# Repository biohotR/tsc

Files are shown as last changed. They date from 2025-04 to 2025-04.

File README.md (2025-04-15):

# OpenBook

## Overview

The project was carried out as part of the Computer Systems Testing course and aims to create a detailed 3D model of an E-Book Reader tablet. We worked on both the internal circuit design and the development of the device’s external appearance, using Fusion 360 software provided by Autodesk.

## Bill of Materials
| Componenta | Link | Datasheet |
|---|---|---|
| BUTTON | [Model](https://industry.panasonic.com/global/en/products/control/switch/light-touch/number/evqpuj02k) | [Datasheet](https://www.lcsc.com/datasheet/lcsc_datasheet_2201121800_PANASONIC-EVQPUJ02K_C2936858.pdf) |
| CAPACITOR | [Model](https://componentsearchengine.com/part-view/R0402%201%25%20100%20K%20(RC0402FR-07100KL)/YAGEO) | [Datasheet](//efaidnbmnnnibpcajpcglclefindmkaj/https://www.resistor.com/assets/pdf/0402tstd.pdf) |
| CPH3225A | [Model](https://www.snapeda.com/parts/CPH3225A/Seiko+Instruments/view-part/?ref=eda) | [Datasheet](https://octopart.com/datasheet/cph3225a-seiko-25340571) |
| EVQPUJ02K | [Model](https://industry.panasonic.com/global/en/products/control/switch/light-touch/number/evqpuj02k) | [Datasheet](https://www.lcsc.com/datasheet/lcsc_datasheet_2201121800_PANASONIC-EVQPUJ02K_C2936858.pdf) |
| KP-1608SURCK | [Model](https://www.snapeda.com/parts/KP-1608SURCK/Kingbright/view-part/?ref=search&t=LED%200603) | [Datasheet](//efaidnbmnnnibpcajpcglclefindmkaj/https://media.elv.com/file/107153_led_surck1608_data.pdf) |
| USBLC6-2SC6Y | [Model](https://www.snapeda.com/parts/USBLC6-2SC6Y/STMicroelectronics/view-part/?ref=eda) | [Datasheet](https://www.digikey.com/en/htmldatasheets/production/1375342/0/0/1/usblc6-2sc6y) |
| SD0805S020S1R0 | [Model](https://ro.mouser.com/ProductDetail/KYOCERA-AVX/SD0805S020S1R0?qs=jCA%252BPfw4LHbpkAoSnwrdjw%3D%3D) | [Datasheet](https://www.alldatasheet.com/view.jsp?Searchword=SD0805S&sField=2) |
| PGB1010603MR | [Model](https://www.snapeda.com/parts/PGB1010603MR/Littelfuse/view-part/?ref=eda) | [Datasheet](https://www.alldatasheet.com/view.jsp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) |
| BD5229G-TR  | [Model](https://componentsearchengine.com/part-view/BD5229G-TR/ROHM%20Semiconductor) | [Datasheet](https://www.lcsc.com/datasheet/lcsc_datasheet_2201131330_ROHM-Semicon-BD5229G-TR_C962636.pdf) |
| XC6220A331MR-G | [Model](https://componentsearchengine.com/part-view/XC6220A331MR-G/Torex) | [Datasheet](https://www.alldatasheet.com/view.jsp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) |
| XC6220A331MR-G | [Model](https://componentsearchengine.com/part-view/XC6220A331MR-G/Torex) | [Datasheet](https://www.alldatasheet.com/view.jsp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) |
| USB4110-GF-A  | [Model](https://componentsearchengine.com/part-view/USB4110-GF-A/GCT%20(GLOBAL%20CONNECTOR%20TECHNOLOGY)) | [Datasheet](//efaidnbmnnnibpcajpcglclefindmkaj/https://gct.co/files/drawings/usb4110.pdf) |
| Adafruit | [Model](https://eu.mouser.com/ProductDetail/Adafruit/4208?qs=PzGy0jfpSMtbScLbr0L5dw%3D%3D) | [Datasheet](https://www.arrow.com/en/manufacturers/adafruit-industries/datasheets) |
| Bobina | [Model](https://store.comet.srl.ro/Catalogue/Product/43497/) | [Datasheet](https://www.scribd.com/document/814581278/Datasheet-Bobina) |
| PFMF | [Model](https://www.mouser.co.uk/ProductDetail/EPCOS-TDK/B72520T0350K062?qs=dEfas%2FXlABIszF52uu7vrg%3D%3D) | [Datasheet](https://ro.mouser.com/c/ds/circuit-protection/thermistors/resettable-fuses-pptc/?m=Schurter&series=PFMF) |
| DMG2305UX-7 | [Model](https://componentsearchengine.com/part-view/DMG2305UX-7/Diodes%20Incorporated) | [Datasheet](//efaidnbmnnnibpcajpcglclefindmkaj/https://www.mouser.com/datasheet/2/115/DMG2305UX-266242.pdf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) |
| Si1308EDL-T1-GE3 | [Model](https://componentsearchengine.com/part-view/SI1308EDL-T1-GE3/Vishay) | [Datasheet](https://www.alldatasheet.com/view.jsp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) |
| R0402 | [Model](https://componentsearchengine.com/part-view/R0402%201%25%20100%20K%20(RC0402FR-07100KL)/YAGEO) | [Datasheet](//efaidnbmnnnibpcajpcglclefindmkaj/https://www.resistor.com/assets/pdf/0402tstd.pdf) |
| BME680 | [Model](https://www.snapeda.com/parts/BME680/Bosch/view-part/?welcome=home) | [Datasheet](//efaidnbmnnnibpcajpcglclefindmkaj/https://www.bosch-sensortec.com/media/boschsensortec/downloads/datasheets/bst-bme680-ds001.pdf) |
| SMD Solder | [Model](https://grabcad.com/library/solder-jumpers-1) | [Datasheet]() |
| W25Q512JVEIQ | [Model](https://www.snapeda.com/parts/ESP32-C6-WROOM-1-N8/Espressif+Systems/view-part/?ref=eda) | [Datasheet](//efaidnbmnnnibpcajpcglclefindmkaj/https://www.mouser.com/datasheet/2/949/W25Q512JV_SPI_RevB_06252019_KMS-2487502.pdf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) |
| ESP32-C6-WROOM-1-N8 | [Model](https://www.snapeda.com/parts/ESP32-C6-WROOM-1-N8/Espressif+Systems/view-part/?ref=eda) | [Datasheet](//efaidnbmnnnibpcajpcglclefindmkaj/https://www.mouser.com/catalog/specsheets/Espressif_ESP32_C6_WROOM_1%20_Datasheet_V0.1_PRELIMINARY_en.pdf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) |
| DS3231SN# | [Model](https://www.snapeda.com/parts/DS3231SN%23/Analog+Devices/view-part/?ref=eda) | [Datasheet](https://www.alldatasheet.com/view.jsp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) |
| MAX17048G+T10 | [Model](https://www.snapeda.com/parts/MAX17048G+T10/Analog+Devices/view-part/?ref=eda) | [Datasheet](https://www.alldatasheet.com/view.jsp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) |
| MCP73831T-5ACI/OT | [Model](https://www.mouser.co.uk/ProductDetail/Microchip-Technology/MCP73831T-5ACI-OT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) | [Datasheet](//efaidnbmnnnibpcajpcglclefindmkaj/https://ww1.microchip.com/downloads/en/DeviceDoc/MCP73831-Family-Data-Sheet-DS20001984H.pdf) |

## Hardware Functionality
The designed circuit includes several key components that ensure the full operation of the E-Book Reader:

1. USB-C Connector with ESD Protection
  
 > Responsible for supplying power to the reader via a USB interface, while also incorporating electrostatic discharge protection to ensure safe and stable operation.
 
2. SD Card
 
 > Acts as the primary storage unit for digital books. It functions at 3.3V and interacts with the microcontroller through the SPI communication bus.
 
3. E-Paper Display and supporting modules: Drive Circuit, EPD Header, and Power Module
  
> The EPD connector interfaces with the microcontroller over SPI and links the display to the system. Power is delivered by a dedicated module that provides multiple voltage levels, while the drive circuit generates the waveforms necessary to update the E-Paper screen.
 
4. BME688 Environmental Sensor
  
 > Capable of detecting temperature, humidity, barometric pressure, and air quality. It operates at 3.3V and uses the I2C protocol for data exchange with the microcontroller.

5. DS3231SN Real-Time Clock Module (RTC)
  
 > Maintains accurate timekeeping, even during power loss, thanks to an onboard 32KHz crystal and optional battery backup. Communication is handled via the I2C protocol, connected through the SDA and SCL lines to the ESP32-C6.

6. External 64MB NOR Flash Memory
  
> Provides additional memory space beyond the microcontroller’s internal storage. Suitable for both long-term data retention and temporary caching. It communicates via SPI.

7.	LDO Voltage Regulator
  
> EStabilizes the power supply by delivering a consistent 3.3V output. Its efficiency and low power usage make it well-suited for portable, battery-operated systems.

8. Voltage Supervisor
  
> Ensures the system starts only under safe voltage conditions by continuously monitoring the power supply and blocking startup if voltage levels are insufficient or erratic.

9. Qwiic/Stemma QT Interface
  
> Simplifies sensor and peripheral integration by allowing multiple I2C devices to be linked in series, reducing the need for complex wiring and enabling plug-and-play functionality.

## Microcontroller ESP32-C6
The entire system is built around the ESP32-C6-WROOM microcontroller, a pre-assembled module with a wide range of integrated capabilities.
* The ESP-WROOM-32 board provides a variety of interfaces for connecting external sensors and components. These include I/O pins, SPI, I2C, and UART, which make it highly versatile for different types of applications. It supports Wi-Fi 6 at 2.4 GHz and features Bluetooth 5 along with a built-in antenna for reliable wireless communication.

* The microcontroller interfaces with various peripheral modules using its dedicated pins, each serving specific functions:

### Power and Reset Control
 > The 3V3 pin powers the module, and GND connects to ground. The EN pin must be set to a HIGH level to activate the module and is typically controlled by a reset button.
### USB-C Interface
 > Since the ESP32-C6 has native USB support, the device communicates directly using the USB_D+ and USB_D- lines, which are mapped to GPIO13 and GPIO14 pins. This eliminates the need for an external USB-to-serial converter.
 ### SD Card Module
> The SD card communicates with the ESP32-C6 via the SPI protocol. The necessary pins for this connection are:
GPIO27 (MISO) – data transfer from the card to the microcontroller,
GPIO7 (MOSI) – data sent to the SD card,
GPIO6 (SCK) – clock signal for synchronization,
GPIO4 (SS_SD) – chip select for the SD card.
### E-Ink Display
> The E-Paper display is connected and controlled using the following pins:
GPIO11 (EPD_CS) – chip select for the display,
GPIO5 (EPD_DC) – display control,
GPIO21 (EPD_RST) – reset pin for the display,
GPIO26 (EPD_BUSY) – pin for checking the display status.
### BME688 Environmental Sensor
> The environmental sensor uses the I2C communication protocol. The pins involved are:
GPIO19 (SDA),GPIO20 (SCL),GPIO17 (I2C_PW) – I2C power control pin.
### UART Communication
> The ESP32-C6 also supports UART communication, which is useful for debugging or connecting to other serial devices. The UART pins are:
TXD0 – data transmission,RXD0 – data reception.
### Other Important Pins
> FLASH_CS – This pin is used to select the external NOR Flash memory via the SPI protocol.
> IO/BOOT – Serves to initiate the boot mode, typically activated through a dedicated button.
> RTC_PWM – Generates Pulse Width Modulation (PWM) signals, controlling the Real-Time Clock (RTC) module's operation.
> RTC_RST – Pin responsible for resetting the RTC module, ensuring it starts from a known state.
> INT_RTC – Interrupt pin used by the RTC module, useful for triggering actions such as waking the system from sleep mode or executing periodic tasks like display updates.

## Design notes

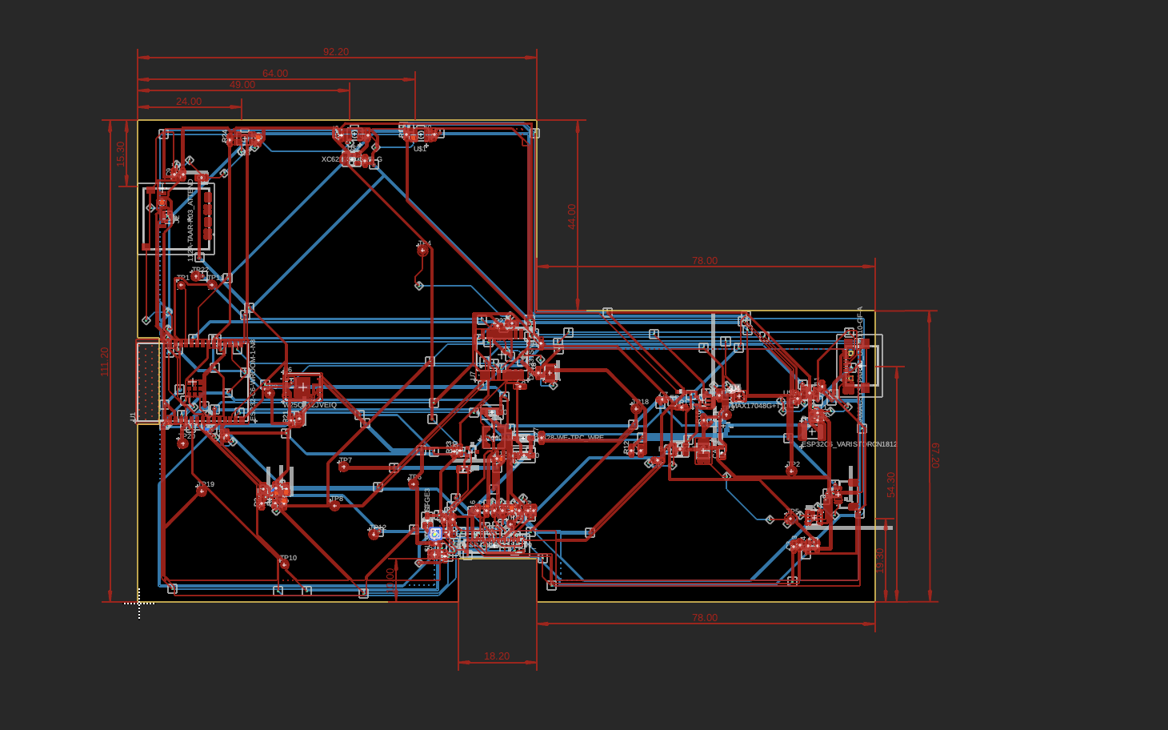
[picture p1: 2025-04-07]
Images/2d.png

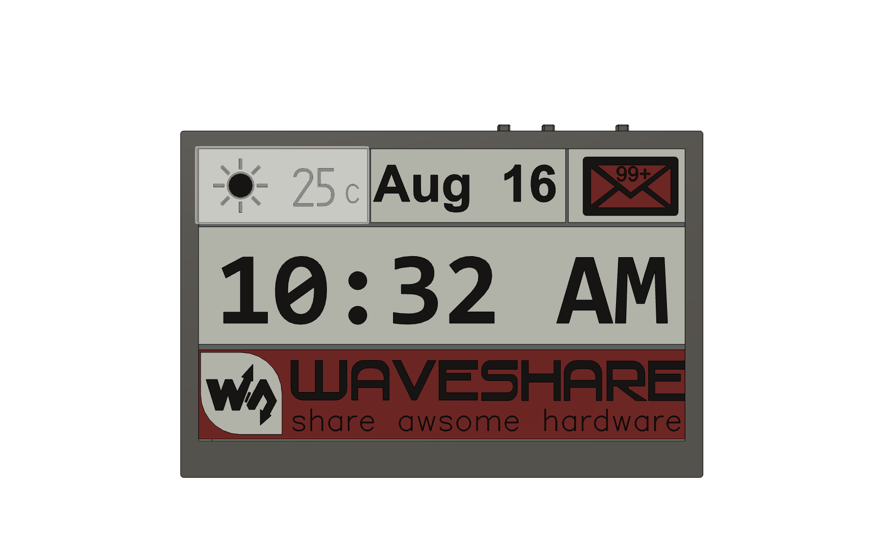
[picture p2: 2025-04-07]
Images/3d_front.png

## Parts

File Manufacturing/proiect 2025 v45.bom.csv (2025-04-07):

Qty | Value | Device | Package | Parts | Description | ARROW_PART_NUMBER | ARROW_PRICE-STOCK | AVAILABILITY | CENTROID_NOT_SPECIFIED | CHECK_PRICES | COPYRIGHT | DATASHEET | DESCRIPTION | DIGIKEY_DESCRIPTION | DIGIKEY_PART_NUMBER | HEIGHT | LEAD_FREE | MANUFACTURER_NAME | MANUFACTURER_PART_NUMBER | MF | MFR_NAME | MOUSER_PART_NUMBER | MOUSER_PRICE-STOCK | MOUSER_TESTING_PART_NUMBER | MOUSER_TESTING_PRICE-STOCK | MP | MPN | PACKAGE | POPULARITY | PREFIX | PRICE | PROD_ID | PURCHASE-URL | ROHS | SNAPEDA_LINK | SPICEMODEL | SPICEPREFIX | TEMPERATURE_RANGE_HIGH | TEMPERATURE_RANGE_LOW | TP_SIGNAL_NAME | VALUE
1 |  | ADAFRUIT_LEDCHIP-LED0603 | ADAFRUIT_CHIP-LED0603 | LED1 | LED
3 |  | EAGLE-LTSPICE_CC0402 | EAGLE-LTSPICE_C0402 | C23, C24, C26 | CAPACITOR, European symbol |  |  |  |  |  |  |  |  |  |  |  |  |  |  |  |  |  |  |  |  |  |  |  |  |  |  |  |  |  |  | NONE | C
23 |  | ESP32_WROVER_EAGLE-LTSPICE_CC0402 | ESP32_WROVER_EAGLE-LTSPICE_C0402 | C1, C2, C3, C4, C6, C7, C8, C9, C11, C12, C13, C14, C15, C16, C17, C18, C19, C20, C21, C22, C25, C27, C29 | CAPACITOR, European symbol |  |  |  |  |  |  |  |  |  |  |  |  |  |  |  |  |  |  |  |  |  |  |  |  |  |  |  |  |  |  | NONE | C
24 |  | ESP32_WROVER_EAGLE-LTSPICE_RR0402 | ESP32_WROVER_EAGLE-LTSPICE_R0402 | R2, R3, R4, R5, R6, R8, R9, R10, R11, R12, R13, R14, R15, R16, R17, R18, R20, R21, R22, R23, R24, R25, R26, R27 | RESISTOR, European symbol |  |  |  |  |  |  |  |  |  |  |  |  |  |  |  |  |  |  |  |  |  |  |  |  |  |  |  |  |  |  | NONE | R
1 |  | RCL_CPOL-EUCT3528 | RCL_CT3528 | CAP3 | POLARIZED CAPACITOR, European symbol |  |  |  |  |  |  |  |  |  |  |  |  |  |  |  |  |  |  |  |  |  |  |  | 0 |  |  |  |  |  |  |  | C
1 |  | SJ | SJ | SJ1 | SMD solder JUMPER |  |  |  |  |  |  |  |  |  |  |  |  |  |  |  |  |  |  |  |  |  |  |  | 3
1 | 112A-TAAR-R03_ATTEND | 112A-TAAR-R03_ATTEND | 112ATAARR03ATTEND | J2 | Micro SD Card Socket, Push-Push Type, Top Mount, SMT, H=1.83mm, 10u |  |  |  |  |  |  |  | Micro SD Card Socket | Push-Push Type | Top Mount | SMT | H=1.83mm | 10u |  |  | 1.9mm |  | ATTEND | 112A-TAAR-R03 ATTEND
2 | 20V/4.2A/52mΩ/1.4W | ESP32_WROVER_SPARKFUN-DISCRETESEMI_MOSFET_PCH-DMG2305UX-7 | ESP32_WROVER_SPARKFUN-DISCRETESEMI_SOT23-3 | Q1, Q3 | P-channel MOSFETs |  |  |  |  |  |  |  |  |  |  |  |  |  |  |  |  |  |  |  |  |  |  |  |  |  |  | TRAN-14388 |  |  |  |  |  |  |  |  | 20V/4.2A/52mΩ/1.4W
1 | 744043680IND_4828-WE-TPC_WRE | 744043680IND_4828-WE-TPC_WRE | IND_4828-WE-TPC_WRE | L1 |  |  |  |  |  |  | Copyright (C) 2024 Ultra Librarian. All rights reserved. |  |  |  |  |  |  |  | 744043680 |  | Wurth Electronics
1 | BD5229G-TR | BD5229G-TR | SOT95P280X125-5N | IC2 | Voltage Detector with Adjustable Delay Time: CMOS processes are utilized to develop high precision, low current consumption CMOS reset ICs that allow arbitrary setting of the delay time. The extensive lineup includes both Nch Open Drain and CMOS output types in a wide range of detection voltages (from 2.3V to 6.0V, in 0.1V steps), enabling selection of the ideal solution based on customer requirements. In addition, the entire series is of course both lead-free and RoHS-compliant. |  |  |  |  |  |  |  | Voltage Detector with Adjustable Delay Time: CMOS processes are utilized to develop high precision | low current consumption CMOS reset ICs that allow arbitrary setting of the delay time. The extensive lineup includes both Nch Open Drain and CMOS output types in a wide range of detection voltages (from 2.3V to 6.0V | in 0.1V steps) | enabling selection of the ideal solution based on customer requirements. In addition | the entire series is of course both lead-free and RoHS-compliant. |  |  | 1.25mm |  | ROHM Semiconductor | BD5229G-TR |  |  | 755-BD5229G-TR | https://www.mouser.co.uk/ProductDetail/ROHM-Semiconductor/BD5229G-TR?qs=4kLU8WoGk0vvnhrrYwdszw%3D%3D
3 | BUTTON_CUSYOMV1 | BUTTON_CUSYOMV1 | MYBUTTON | U$1, U$2, U$3
1 | CPH3225A | CPH3225A | CAPCP3225X100N | C30 | Cap 0.011F 3.3V 1210 Flat Check availability |  |  | Not in stock |  | https://www.snapeda.com/parts/CPH3225A/Seiko+Instruments/view-part/?ref=eda |  |  | 11 mF (EDLC) Supercapacitor 3.3 V 1210 (3225 Metric) - - |  |  |  |  |  |  | Seiko Instruments |  |  |  |  |  | CPH3225A |  | 1210 Seiko |  |  | None |  | https://www.snapeda.com/api/url_track_click_mouser/?unipart_id=562593&manufacturer=Seiko Instruments&part_name=CPH3225A&search_term=None |  | https://www.snapeda.com/parts/CPH3225A/Seiko+Instruments/view-part/?ref=snap
1 | DS3231SN# | DS3231SN# | SOIC127P1032X265-16N | U7 | Real Time Clock Serial 16-Pin SOIC W T/R Check availability |  |  | In Stock |  | https://www.snapeda.com/parts/DS3231SN%23/Analog+Devices/view-part/?ref=eda |  |  | Extremely Accurate I²C-Integrated RTC/TCXO/Crystal |  |  |  |  |  |  | Analog Devices |  |  |  |  |  | DS3231SN# |  | SOIC-16 Maxim |  |  | None |  | https://www.snapeda.com/api/url_track_click_mouser/?unipart_id=99048&manufacturer=Analog Devices&part_name=DS3231SN#&search_term=None |  | https://www.snapeda.com/parts/DS3231SN%23/Analog+Devices/view-part/?ref=snap
1 | ESP32-C6-WROOM-1-N8 | ESP32-C6-WROOM-1-N8 | XCVR_ESP32-C6-WROOM-1-N8 | U1 | Check availability |  |  | In Stock |  | https://www.snapeda.com/parts/ESP32-C6-WROOM-1-N8/Espressif+Systems/view-part/?ref=eda |  |  | Multiprotocol Modules ESP32-C6 module | Wi-Fi 6 in 2.4 GHz band | Bluetooth 5 | Zigbee 3.0 and Thread. ESP34-WROOM Compatible - ENGINEERING SAMPLE |  |  |  |  |  |  | Espressif Systems |  |  |  |  |  | ESP32-C6-WROOM-1-N8 |  | None |  |  | None |  |  |  | https://www.snapeda.com/parts/ESP32-C6-WROOM-1-N8/Espressif+Systems/view-part/?ref=snap
1 | ESP32C6_VARISTORCN1812 | ESP32C6_VARISTORCN1812 | ESP32C6_VARISTOR_CT/CN1812 | R_SPEC | VARISTOR |  |  |  |  |  |  |  |  |  |  |  |  |  |  |  |  |  |  |  |  |  |  |  | 0
2 | ESP32_WROVER_AVX---SD0805S020S1R0_AVX_SD0805S020S1R0_0_0AVX_SD0805S020S1R0_0_0 | ESP32_WROVER_AVX---SD0805S020S1R0_AVX_SD0805S020S1R0_0_0AVX_SD0805S020S1R0_0_0 | ESP32_WROVER_AVX---SD0805S020S1R0_AVX_SD0805S020S1R0_0 | D2, D13 | Schottky Barrier Rectifier Diode |  |  |  | No |  |  | http://datasheets.avx.com/schottky.pdf |  | DIODE SCHOTTKY 20V 1A 0805 | 478-7800-1-ND |  | yes |  |  | AVX |  | 581-SD0805S020S1R0 |  |  |  |  |  | 0805 (2012 metric) |  | D |  |  |  | yes |  |  |  | +125°C | -55°C
1 | ESP32_WROVER_BME680_BME680 | ESP32_WROVER_BME680_BME680 | ESP32_WROVER_BME680_PSON80P300X300X100-8N | U3 | Integrated Environmental Unit |  |  | Unavailable |  |  |  |  | Integrated Environmental Unit |  |  |  |  |  |  | Bosch Sensortec |  |  |  |  |  | BME680 |  | LGA-8 Bosch Tools |  |  | None
1 | ESP32_WROVER_SPARKFUN-IC-POWER_MCP73831 | ESP32_WROVER_SPARKFUN-IC-POWER_MCP73831 | ESP32_WROVER_SPARKFUN-IC-POWER_SOT23-5 | U2 | MCP73831T Li-Ion, Li-Pol Controller |  |  |  |  |  |  |  |  |  |  |  |  |  |  |  |  |  |  |  |  |  |  |  |  |  |  | IC-09995
1 | FH34SRJ-24S-0.5SH_99_ | FH34SRJ-24S-0.5SH_99_ | FH34SRJ24S05SH99 | J3 | (0.50mm) Surface Mount, Right Angle |  |  |  |  |  |  |  | 24 Position FFC | FPC Connector Contacts | (0.50mm) Surface Mount | Right Angle |  |  | 1.1mm |  | Hirose | FH34SRJ-24S-0.5SH(99) |  |  | 798-FH34SRJ24S05SH99 | https://www.mouser.co.uk/ProductDetail/Hirose-Connector/FH34SRJ-24S-0.5SH99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
1 | MAX17048G+T10 | MAX17048G+T10 | SON50P200X200X80-9N | U4 | Check availability |  |  | In Stock |  | https://www.snapeda.com/parts/MAX17048G+T10/Analog+Devices/view-part/?ref=eda |  |  | 3µA 1-Cell/2-Cell Fuel Gauge with ModelGauge |  |  |  |  |  |  | Analog Devices |  |  |  |  |  | MAX17048G+T10 |  | TDFN-8 Maxim |  |  | None |  | https://www.snapeda.com/api/url_track_click_mouser/?unipart_id=329239&manufacturer=Analog Devices&part_name=MAX17048G+T10&search_term=None |  | https://www.snapeda.com/parts/MAX17048G+T10/Analog+Devices/view-part/?ref=snap
3 | MBR0530 | MBR0530 | SOD3716X135N | D3, D4, D5 | ON SEMICONDUCTOR - MBR0530 - DIODE, SCHOTTKY, 0.5A, 30V, SOD-123 |  |  | In Stock |  | https://www.snapeda.com/parts/MBR0530/Onsemi/view-part/?ref=eda |  |  | Diode Schottky 30 V 500mA Surface Mount SOD-123 |  |  |  |  |  |  | ON Semiconductor |  |  |  |  |  | MBR0530 |  | SOD-123-2 ON Semiconductor |  |  | None |  | https://www.snapeda.com/api/url_track_click_mouser/?unipart_id=179458&manufacturer=ON Semiconductor&part_name=MBR0530&search_term=None |  | https://www.snapeda.com/parts/MBR0530/Onsemi/view-part/?ref=snap
6 | PGB1010603MR | PGB1010603MR | DIOC1608X36N | D7, D8, D9, D10, D11, D12 | Check availability |  |  | In Stock |  | https://www.snapeda.com/parts/PGB1010603MR/Littelfuse/view-part/?ref=eda |  |  | 150V (Typ) Clamp - Ipp Tvs Diode Surface Mount 0603 (1608 Metric) |  |  |  |  |  |  | Littelfuse Inc. |  |  |  |  |  | PGB1010603MR |  | 0603 Littelfuse Inc. |  |  | None |  | https://www.snapeda.com/api/url_track_click_mouser/?unipart_id=5659453&manufacturer=Littelfuse Inc.&part_name=PGB1010603MR&search_term=None |  | https://www.snapeda.com/parts/PGB1010603MR/Littelfuse/view-part/?ref=snap
1 | QWIIC_RIGHT_ANGLE | QWIIC_CONNECTORJS-1MM | JST04_1MM_RA | J5 | SparkFun I2C Standard Qwiic Connector |  |  |  |  |  |  |  |  |  |  |  |  |  |  |  |  |  |  |  |  |  |  |  |  |  |  | CONN-13694 |  |  |  |  |  |  |  |  | QWIIC_RIGHT_ANGLE
1 | SAMACSYS_PARTS_USB4110-GF-A | SAMACSYS_PARTS_USB4110-GF-A | SAMACSYS_PARTS_USB4110GFA | J1 | CONN USB 2.0 TYPE-C R/A SMT |  |  |  |  |  |  |  | CONN USB 2.0 TYPE-C R/A SMT |  |  | 3.26mm |  | GCT (GLOBAL CONNECTOR TECHNOLOGY) | USB4110-GF-A |  |  | 640-USB4110-GF-A | https://www.mouser.co.uk/ProductDetail/GCT/USB4110-GF-A?qs=KUoIvG%2F9IlYiZvIXQjyJeA%3D%3D
1 | SI1308EDL-T1-GE3 | SI1308EDL-T1-GE3 | SOT65P210X110-3N | TRANSIST | MOSFET N-Ch 30V 1.5A TrenchFET SC70 Vishay Si1308EDL-T1-GE3 N-channel MOSFET Transistor, 1.5 A, 30 V, 3-Pin SC-70 |  |  | In Stock |  | https://www.snapeda.com/parts/SI1308EDL-T1-GE3/Vishay+Siliconix/view-part/?ref=eda |  |  | Si1308EDL-T1-GE3 N-channel MOSFET Transistor | 1.5 A | 30 V | 3-Pin SC-70 | Siliconix / Vishay SI1308EDL-T1-GE3 |  |  |  |  |  |  | Vishay Siliconix |  |  |  |  |  | SI1308EDL-T1-GE3 |  | SOT-323 Vishay Semiconductor |  |  | None |  | https://www.snapeda.com/api/url_track_click_mouser/?unipart_id=274603&manufacturer=Vishay Siliconix&part_name=SI1308EDL-T1-GE3&search_term=None |  | https://www.snapeda.com/parts/SI1308EDL-T1-GE3/Vishay+Siliconix/view-part/?ref=snap
17 | TPTP20R | TPTP20R | TP20R | TP1, TP2, TP3, TP4, TP5, TP6, TP7, TP8, TP9, TP10, TP11, TP12, TP18, TP19, TP20, TP21, TP22 | Test pad |  |  |  |  |  |  |  |  |  |  |  |  |  |  |  |  |  |  |  |  |  |  |  | 2
1 | USBLC6-2SC6Y | USBLC6-2SC6Y | SOT95P280X145-6N | D1 | Low Cap. ESD Protection Auto SOT-23-6 STMicroelectronics USBLC6-2SC6Y, Dual Uni-Directional TVS Diode Array, 6-Pin SOT-23 |  |  | In Stock |  | https://www.snapeda.com/parts/USBLC6-2SC6Y/STMicroelectronics/view-part/?ref=eda |  |  | 17V Clamp 5A (8/20µs) Ipp Tvs Diode Surface Mount SOT-23-6 |  |  |  |  |  |  | STMicroelectronics |  |  |  |  |  | USBLC6-2SC6Y |  | SOT-23-6 STMicroelectronics |  |  | None |  |  |  | https://www.snapeda.com/parts/USBLC6-2SC6Y/STMicroelectronics/view-part/?ref=snap
1 | W25Q512JVEIQ | W25Q512JVEIQ | SON127P600X800X80-9N | U6 | Check availability |  |  | In Stock |  | https://www.snapeda.com/parts/W25Q512JVEIQ/Winbond+Electronics/view-part/?ref=eda |  |  | FLASH - NOR Memory IC 512Mb (64M x 8) SPI - Quad I/O 133 MHz 8-WSON (8x6) |  |  |  |  |  |  | Winbond Electronics |  |  |  |  |  | W25Q512JVEIQ |  | Package |  |  | None |  |  |  | https://www.snapeda.com/parts/W25Q512JVEIQ/Winbond+Electronics/view-part/?ref=snap
1 | XC6220A331MR-G | XC6220A331MR-G | SOT95P280X120-5N | IC1 | LDO Voltage Regulators |  |  |  |  |  |  |  | LDO Voltage Regulators |  |  | 1.2mm |  | Torex | XC6220A331MR-G |  |  | 865-XC6220A331MR-G | https://www.mouser.co.uk/ProductDetail/Torex-Semiconductor/XC6220A331MR-G?qs=AsjdqWjXhJ8ZSWznL1J0gg%3D%3D

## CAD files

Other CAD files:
Mechanical/OpenBook Enclosure v2.f3z

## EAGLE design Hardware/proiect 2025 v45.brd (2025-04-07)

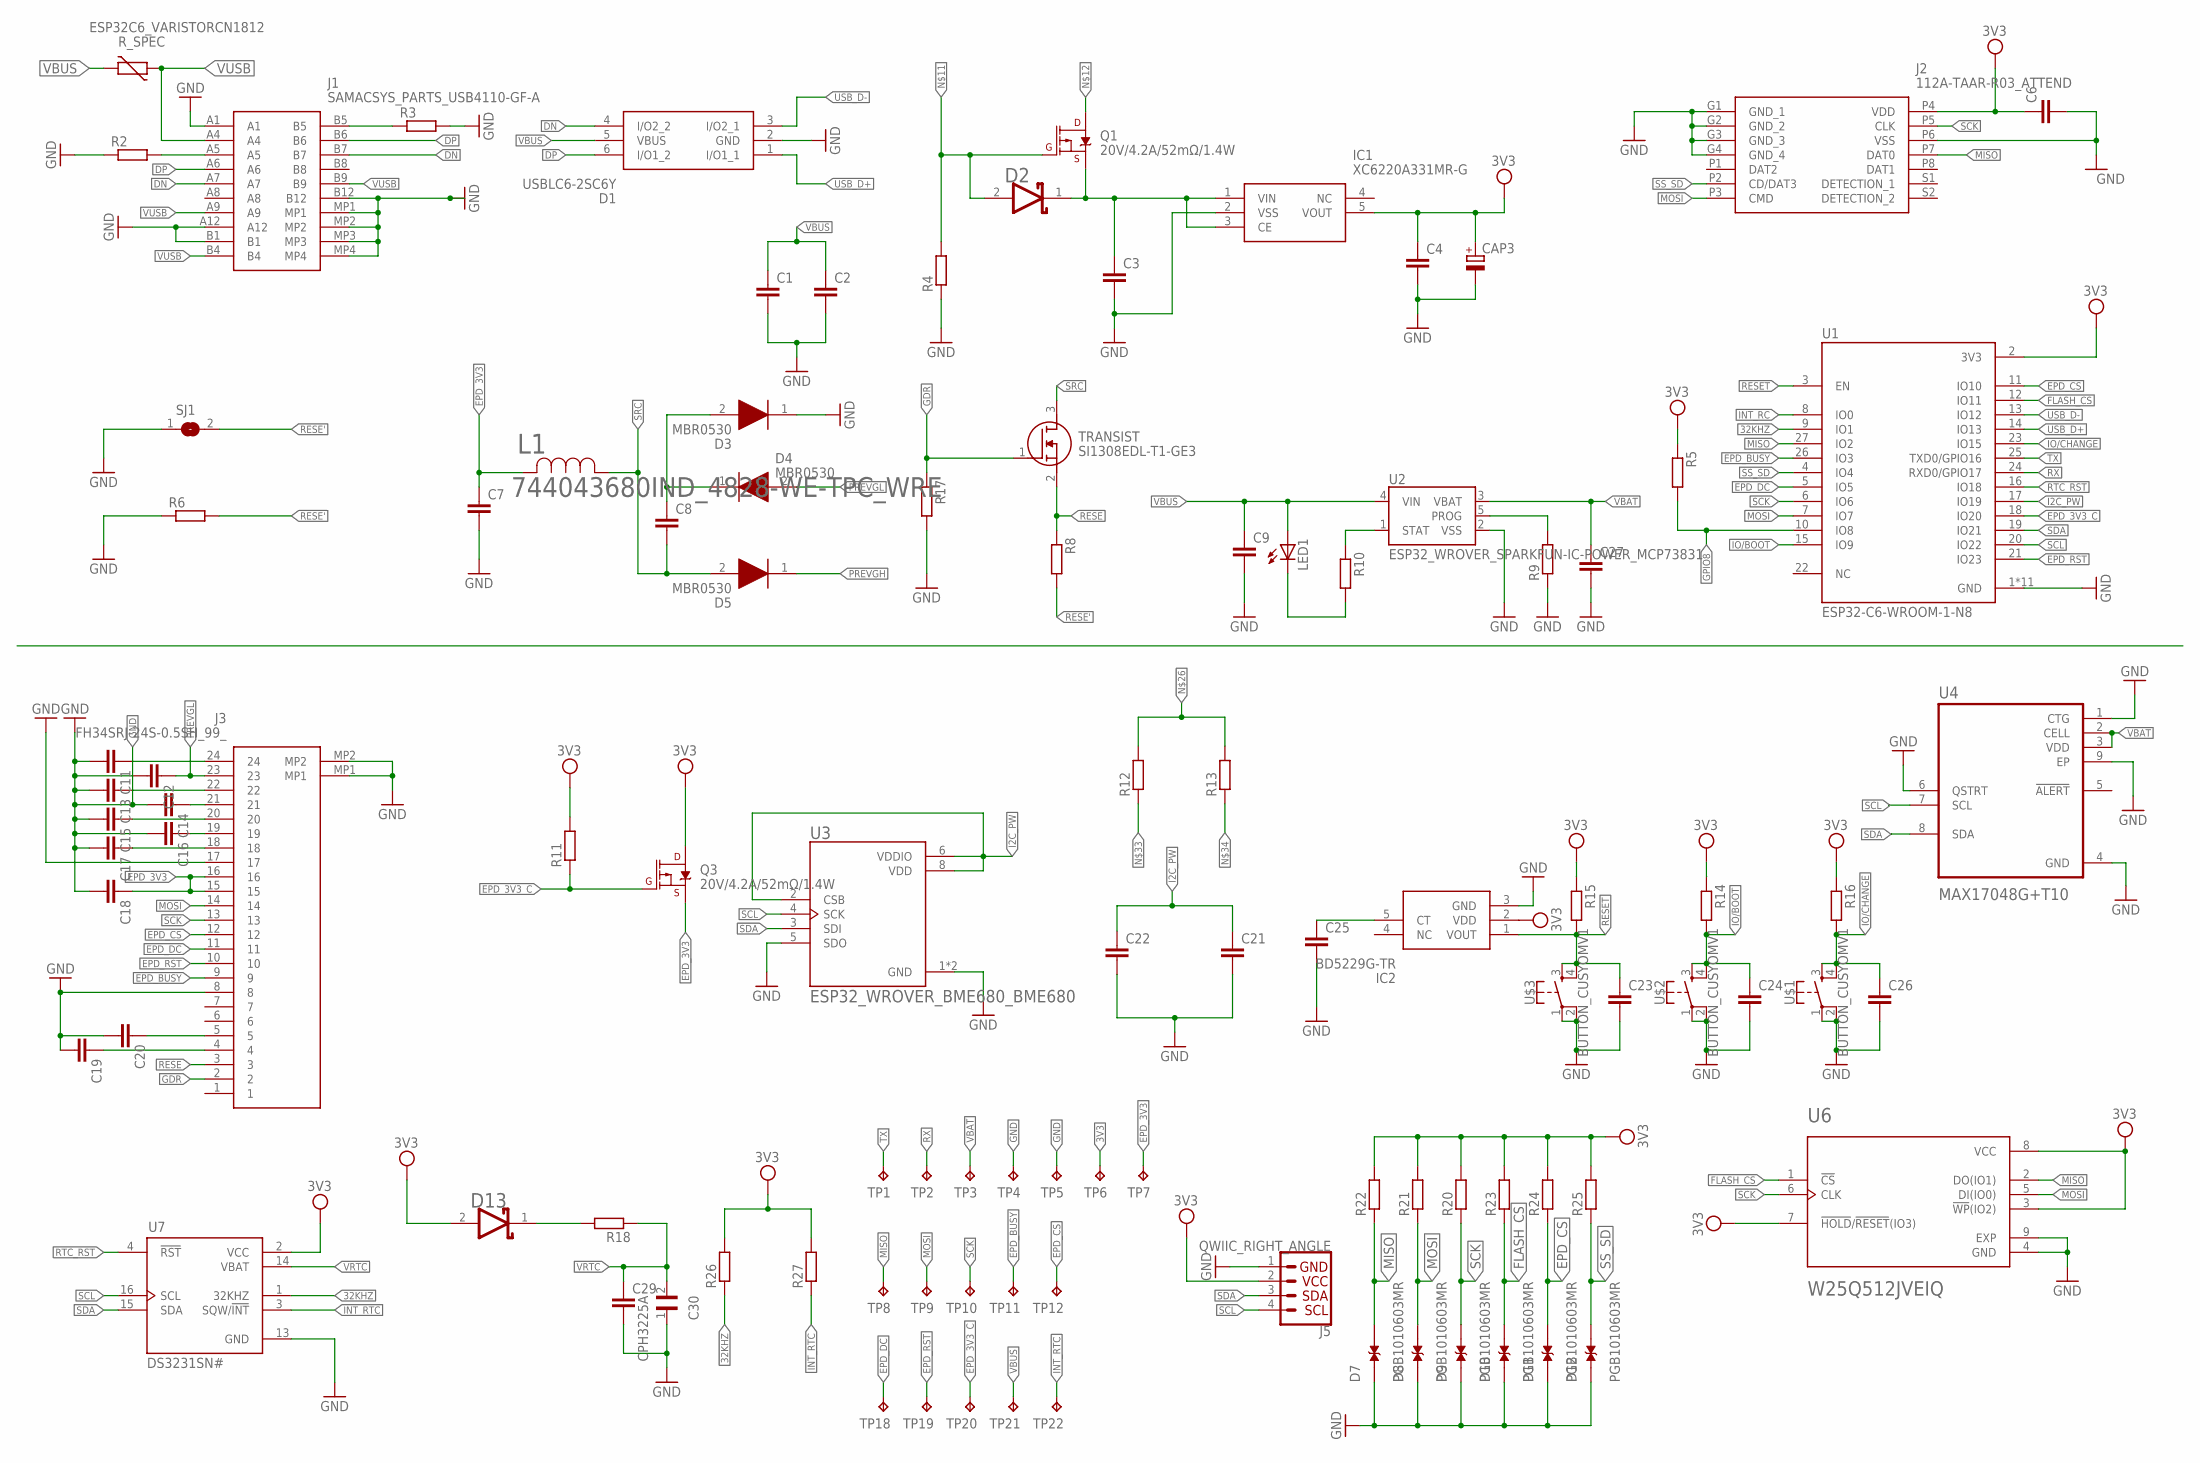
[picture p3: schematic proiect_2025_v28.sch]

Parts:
C1, C2, C3, C4, C6, C7, C8, C9, C11, C12, C13, C14, C15, C16, C17, C18, C19, C20, C21, C22, C25, C27, C29: ESP32_WROVER_EAGLE-LTSPICE_CC0402; ESP32_WROVER_EAGLE-LTSPICE_C0402
C23, C24, C26: EAGLE-LTSPICE_CC0402; EAGLE-LTSPICE_C0402
C30: CPH3225A; CAPCP3225X100N
CAP3: RCL_CPOL-EUCT3528; RCL_CT3528
D1: USBLC6-2SC6Y; SOT95P280X145-6N
D2, D13: ESP32_WROVER_AVX---SD0805S020S1R0_AVX_SD0805S020S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; ESP32_WROVER_AVX---SD0805S020S1R0_AVX_SD0805S020S1R0_0
D3, D4, D5: MBR0530; SOD3716X135N
D7, D8, D9, D10, D11, D12: PGB1010603MR; DIOC1608X36N
IC1: XC6220A331MR-G; SOT95P280X120-5N
IC2: BD5229G-TR; SOT95P280X125-5N
J1: SAMACSYS_PARTS_USB4110-GF-A; SAMACSYS_PARTS_USB4110GFA
J2: 112A-TAAR-R03_ATTEND; 112ATAARR03ATTEND
J3: FH34SRJ-24S-0.5SH_99_; FH34SRJ24S05SH99
J5: QWIIC_RIGHT_ANGLE; JST04_1MM_RA
L1: 744043680IND_4828-WE-TPC_WRE; IND_4828-WE-TPC_WRE
LED1: ADAFRUIT_LEDCHIP-LED0603; ADAFRUIT_CHIP-LED0603
Q1, Q3: 20V/4.2A/52mΩ/1.4W; ESP32_WROVER_SPARKFUN-DISCRETESEMI_SOT23-3
R2, R3, R4, R5, R6, R8, R9, R10, R11, R12, R13, R14, R15, R16, R17, R18, R20, R21, R22, R23, R24, R25, R26, R27: ESP32_WROVER_EAGLE-LTSPICE_RR0402; ESP32_WROVER_EAGLE-LTSPICE_R0402
R_SPEC: ESP32C6_VARISTORCN1812; ESP32C6_VARISTOR_CT/CN1812
SJ1: SJ
TP1, TP2, TP3, TP4, TP5, TP6, TP7, TP8, TP9, TP10, TP11, TP12, TP18, TP19, TP20, TP21, TP22: TPTP20R; TP20R
TRANSIST: SI1308EDL-T1-GE3; SOT65P210X110-3N
U1: ESP32-C6-WROOM-1-N8; XCVR_ESP32-C6-WROOM-1-N8
U2: ESP32_WROVER_SPARKFUN-IC-POWER_MCP73831; ESP32_WROVER_SPARKFUN-IC-POWER_SOT23-5
U3: ESP32_WROVER_BME680_BME680; ESP32_WROVER_BME680_PSON80P300X300X100-8N
U4: MAX17048G+T10; SON50P200X200X80-9N
U6: W25Q512JVEIQ; SON127P600X800X80-9N
U7: DS3231SN#; SOIC127P1032X265-16N
U$1, U$2, U$3: BUTTON_CUSYOMV1; MYBUTTON

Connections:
3V3: C4.1, C6.1, CAP3.+, D13.2 (ANODE), IC1.5 (VOUT), IC2.2 (VDD), J2.P4 (VDD), J5.2, Q3.3 (D), R5.1, R11.2, R14.1, R15.1, R16.1, R20.2, R21.2, R22.2, R23.2, R24.2, R25.2, R26.2, R27.2, TP6.TP, U1.2 (3V3), U6.3 (!WP!(IO2)), U6.7 (!HOLD!/!RESET!(IO3)), U6.8 (VCC), U7.2 (VCC)
32KHZ: R26.1, U1.9 (IO1), U7.1 (32KHZ)
DN: D1.4 (I/O2_2), J1.B7
DP: D1.6 (I/O1_2), J1.A6, J1.B6
EPD_3V3: C7.1, C18.1, J3.15, J3.16, L1.2, Q3.2 (S), TP7.TP
EPD_3V3_C: Q3.1 (G), R11.1, TP20.TP, U1.18 (IO20)
EPD_BUSY: J3.9, TP11.TP, U1.26 (IO3)
EPD_CS: D11.2, J3.12, R24.1, TP12.TP, U1.11 (IO10)
EPD_DC: J3.11, TP18.TP, U1.5 (IO5)
EPD_RST: J3.10, TP19.TP, U1.21 (IO23)
FLASH_CS: D10.2, R23.1, U1.12 (IO11), U6.1 (!CS)
GDR: J3.2, R17.1, TRANSIST.1 (G)
GND: C1.2, C2.2, C3.2, C4.2, C6.2, C7.2, C9.2, C11.2, C12.2, C13.2, C14.2, C15.2, C16.2, C17.2, C18.2, C19.2, C20.2, C21.2, C22.2, C23.2, C24.2, C25.2, C26.2, C27.2, C29.2, C30.1, CAP3.-, D1.2 (GND), D3.1 (K), D7.1, D8.1, D9.1, D10.1, D11.1, D12.1, IC1.2 (VSS), IC2.3 (GND), J1.A1, J1.A12, J1.B1, J1.B12, J1.MP1, J1.MP2, J1.MP3, J1.MP4, J2.G1 (GND_1), J2.G2 (GND_2), J2.G3 (GND_3), J2.G4 (GND_4), J2.P6 (VSS), J3.8, J3.17, J3.MP1, J3.MP2, J5.1, R2.1, R3.2, R4.1, R6.1, R9.1, R17.2, SJ1.1, TP4.TP, TP5.TP, U1.1 (GND), U1.28 (GND), U1.29_1 (GND), U1.29_2 (GND), U1.29_3 (GND), U1.29_4 (GND), U1.29_5 (GND), U1.29_6 (GND), U1.29_7 (GND), U1.29_8 (GND), U1.29_9 (GND), U2.2 (VSS), U3.1 (GND), U3.5 (SDO), U3.7 (GND), U4.1 (CTG), U4.4 (GND), U4.6 (QSTRT), U4.9 (EP), U6.4 (GND), U6.9 (EXP), U7.13 (GND), U$1.1, U$1.2, U$2.1, U$2.2, U$3.1, U$3.2
GPIO8: R5.2, U1.10 (IO8)
I2C_PW: C21.1, C22.1, U1.17 (IO19), U3.2 (CSB), U3.6 (VDDIO), U3.8 (VDD)
INT_RC: U1.8 (IO0)
INT_RTC: R27.1, TP22.TP, U7.3 (SQW/!INT)
IO/BOOT: C24.1, R14.2, U1.15 (IO9), U$2.3, U$2.4
IO/CHANGE: C26.1, R16.2, U1.23 (IO15), U$1.3, U$1.4
MISO: D7.2, J2.P7 (DAT0), R22.1, TP8.TP, U1.27 (IO2), U6.2 (DO(IO1))
MOSI: D8.2, J2.P3 (CMD), J3.14, R21.1, TP9.TP, U1.7 (IO7), U6.5 (DI(IO0))
unnamed: J1.B5, R3.1
unnamed: J1.A5, R2.2
unnamed: C8.1, D3.2 (A), D4.1 (K)
unnamed: D2.2 (ANODE), Q1.1 (G), R4.2
unnamed: C3.1, D2.1 (CATHODE), IC1.1 (VIN), IC1.3 (CE), Q1.2 (S)
unnamed: C25.1, IC2.5 (CT)
unnamed: LED1.C, R10.2
unnamed: R10.1, U2.1 (STAT)
unnamed: R9.2, U2.5 (PROG)
unnamed: R12.2, R13.2
unnamed: C20.1, J3.5
unnamed: C11.1, J3.24
unnamed: C19.1, J3.4
unnamed: C13.1, J3.22
unnamed: D13.1 (CATHODE), R18.2
unnamed: C14.1, J3.21
unnamed: C15.1, J3.20
unnamed: C16.1, J3.19
unnamed: C17.1, J3.18
PREVGH: D5.1 (K)
PREVGL: C12.1, D4.2 (A), J3.23
RESE: J3.3, R8.1, TRANSIST.2 (S)
RESE': R6.2, R8.2, SJ1.2
RESET: C23.1, IC2.1 (VOUT), R15.2, U1.3 (EN), U$3.3, U$3.4
RTC_RST: U1.16 (IO18), U7.4 (!RST)
RX: TP2.TP, U1.24 (RXD0/GPIO17)
SCK: D9.2, J2.P5 (CLK), J3.13, R20.1, TP10.TP, U1.6 (IO6), U6.6 (CLK)
SCL: J5.4, U1.20 (IO22), U3.4 (SCK), U4.7 (SCL), U7.16 (SCL)
SDA: J5.3, U1.19 (IO21), U3.3 (SDI), U4.8 (SDA), U7.15 (SDA)
SRC: C8.2, D5.2 (A), L1.1, TRANSIST.3 (D)
SS_SD: D12.2, J2.P2 (CD/DAT3), R25.1, U1.4 (IO4)
TX: TP1.TP, U1.25 (TXD0/GPIO16)
USB_D+: D1.1 (I/O1_1), U1.14 (IO13)
USB_D-: D1.3 (I/O2_1), U1.13 (IO12)
VBAT: C27.1, TP3.TP, U2.3 (VBAT), U4.2 (CELL), U4.3 (VDD)
VBUS: C1.1, C2.1, C9.1, D1.5 (VBUS), LED1.A, R_SPEC.2, TP21.TP, U2.4 (VIN)
VRTC: C29.1, C30.2, R18.1, U7.14 (VBAT)
VUSB: J1.A4, J1.A9, J1.B4, J1.B9, R_SPEC.1

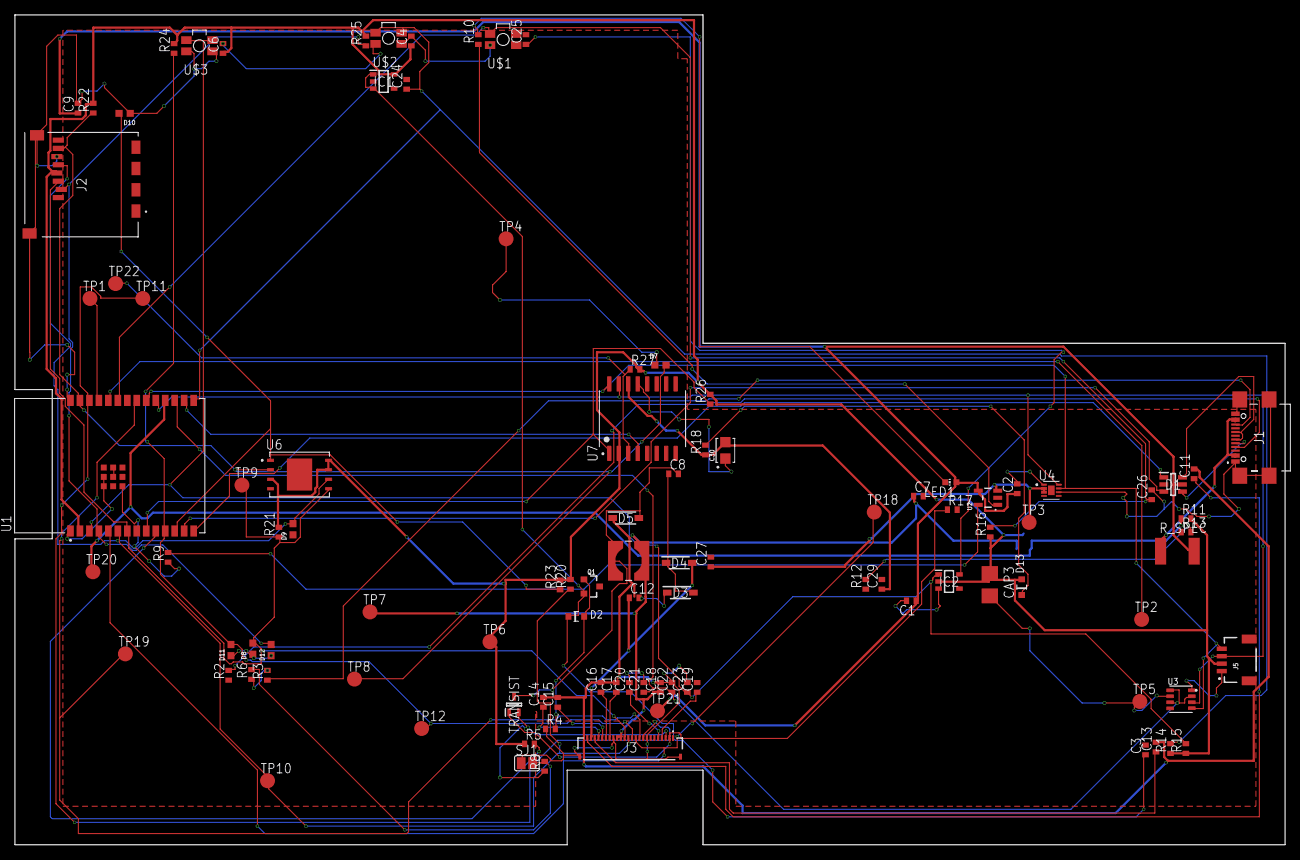
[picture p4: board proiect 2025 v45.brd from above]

Board: 2 copper layers, 170.2 x 111.2 mm, 103 parts (1 on the bottom side), 57 nets.

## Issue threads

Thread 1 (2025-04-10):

Denumiri componente si titluri schematic

elenaghita, 2025-04-10:
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
Nu ai pus nicaieri titlurile sectiunilor din openbook si nu ai denumit corect unele componente (de exemplu : in poza , in loc de C1_BAT1 ai scris C3 si in loc de IC4 ai scris IC1 ).Ai si cateva label-uri care nu au nume.

Closed 2025-04-15.

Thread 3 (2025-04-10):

Valori componente

elenaghita, 2025-04-10:
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
Ai foarte multe componente care nu au valori ,asigura-te ca ai incarcat versiunea curenta a schematic-ului.

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
Dupa ce dai valori componentelor poti da validate ERC ca sa iti dispara din warning-uri.

Closed 2025-04-15.

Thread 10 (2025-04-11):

Errors+warnings PCB 2D

elenaghita, 2025-04-11:
Erorile si warnings-urile de tip Wire Stub trebuie rezolvate :
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

Closed 2025-04-15.

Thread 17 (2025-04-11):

README

elenaghita, 2025-04-11:
In README lipsesc :
-in folderul Mechanical lipseste exploded view (.step) (ai pus tot dispozitivul , trebuia sa fie exploded)
-in folderul de imagini , lipsesc randarile PCB-ului 3D si ale openbook-ului complet 3D
-diagrama bloc cu toate componentele si cum sunt legate
-BOM-ul sub formă de tabel cu link-urile catre componentele si datasheet-ul lor
-descrierea in detaliu a componentelor folosite si functionalitatile hardware
-descrierea in detaliu a pinilor pentru ESP32-C6

Closed 2025-04-15.

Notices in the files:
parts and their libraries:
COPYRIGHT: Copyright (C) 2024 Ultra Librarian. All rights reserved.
